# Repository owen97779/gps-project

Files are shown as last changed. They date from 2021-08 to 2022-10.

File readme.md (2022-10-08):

# GPS Project
## Introduction
The aim of the project is to design an open-source IoT-enabled GPS that can be used to provide coordinates at the behest of the user. The success of the device can be quantified by these factors:

### Hardware
- [ ] Open-source design
- [ ] Small form-factor and weight
- [ ] Durable
- [ ] Physical indicators of task completion
- [ ] ESD protection
- [ ] USB-C charging
- [ ] Wifi communication
- [ ] Cellular IoT communication
- [ ] Local storage
- [ ] Low power consumption
- [ ] Passing EMC tests
- [ ] Widely available and low cost components

### Software
- [ ] Open-source software
- [ ] OTA firmware updates
- [ ] Customisable GPS tracking intervals
- [ ] MQTT protocol adoption
- [ ] API integration

## Design
Multiple prototypes are being developed, each prototype with the aim of improving each design based on the limitations of the current in achieving the goals outlined above. The process can be viewed on [my blog](https://owen97779.github.io/GPS.html).

## Repository Branches
There are multiple branches working on different aspects of the project. Finalised builds will be merged onto the main branch.

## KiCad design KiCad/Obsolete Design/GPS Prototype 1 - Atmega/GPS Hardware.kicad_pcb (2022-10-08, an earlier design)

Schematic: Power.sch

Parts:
C1: 1u; C_0402_1005Metric_Pad0.74x0.62mm_HandSolder
C2, C6: 22u; C_0402_1005Metric_Pad0.74x0.62mm_HandSolder
C3: 47n; C_0402_1005Metric_Pad0.74x0.62mm_HandSolder
C4: 4u7; C_0402_1005Metric_Pad0.74x0.62mm_HandSolder
C5: 10u; C_0402_1005Metric_Pad0.74x0.62mm_HandSolder
C7: 220u; CP_EIA-3528-12_Kemet-T_Pad1.50x2.35mm_HandSolder
C8, C9: 0u1; C_0603_1608Metric_Pad1.08x0.95mm_HandSolder
D1: LED; LED_0603_1608Metric_Pad1.05x0.95mm_HandSolder
J1: USB_C_Receptacle_USB2.0; USB_C_Receptacle_HRO_TYPE-C-31-M-12
J5: B2B-XH-A(LF)(SN); JST_B2B-XH-A(LF)(SN); PARTREV 1.0
L1: 2u2; IND_SRP0312-2R2K
R1, R2: 5k1; R_0402_1005Metric_Pad0.72x0.64mm_HandSolder
R3, R4, R5: 4k7; R_0402_1005Metric_Pad0.72x0.64mm_HandSolder
R6, R7: 10k; R_0402_1005Metric_Pad0.72x0.64mm_HandSolder
R8: 250; R_0402_1005Metric_Pad0.72x0.64mm_HandSolder
R9: 10k; R_0603_1608Metric_Pad0.98x0.95mm_HandSolder
R10: 5k23; R_0402_1005Metric_Pad0.72x0.64mm_HandSolder
R11: 32k; R_0603_1608Metric_Pad0.98x0.95mm_HandSolder
TH1: Thermistor_NTC 10K; R_0805_2012Metric_Pad1.20x1.40mm_HandSolder
U1: ESD122DMX; IC_ESD122DMXR
U3: BQ24295; QFN50P400X400X100-25N
U4: LM3480-3.3; SOT-23

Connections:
D+: J1.A6 (D+), J1.B6 (D+), U1.1, U3.2
D-: J1.A7 (D-), J1.B7 (D-), U1.2, U3.3
GND: C1.2, C2.2, C4.2, C5.2, C6.2, C7.2, C8.2, C9.2, J1.A1 (GND), J1.A12 (GND), J1.B1 (GND), J1.B12 (GND), J1.S1 (SHIELD), J5.2, R1.1, R2.1, R6.2, R7.1, R11.2, TH1.2, U1.3, U3.17, U3.18, U3.25, U4.3 (GND); also elsewhere on the board
INT_Power: R5.1, U3.7; also elsewhere on the board
unnamed: C2.1, U3.23
unnamed: C3.1, U3.21
unnamed: C3.2, L1.1, U3.19, U3.20
unnamed: C4.1, R10.1, U3.22
unnamed: C5.1, J5.1, U3.13, U3.14
unnamed: D1.1 (K), R8.1
unnamed: J1.A5 (CC1), R1.2
unnamed: J1.B5 (CC2), R2.2
unnamed: R6.1, U3.9
unnamed: R7.2, U3.10
unnamed: R8.2, U3.4
unnamed: R9.1, U3.8
unnamed: R10.2, R11.1, TH1.1, U3.11
SCL_Power: R3.1, U3.5; also elsewhere on the board
SDA_Power: R4.2, U3.6; also elsewhere on the board
SYS: C6.1, C7.1, C8.1, D1.2 (A), L1.2, R9.2, U3.15, U3.16, U4.2 (VI); also elsewhere on the board
VBUS: C1.1, J1.A4 (VBUS), J1.A9 (VBUS), J1.B4 (VBUS), J1.B9 (VBUS), U3.1, U3.24

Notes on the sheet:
Check if switch is required
Different capacitor values for low impedance at a range of frequencies

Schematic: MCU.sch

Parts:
C10, C11, C12, C13, C16, C17: 0u1; C_0402_1005Metric_Pad0.74x0.62mm_HandSolder
C14, C15: 22p; C_0603_1608Metric_Pad1.08x0.95mm_HandSolder
J2: Conn_01x06_Male; PinHeader_2x03_P1.00mm_Vertical_SMD
R12, R13, R14: 330; R_0402_1005Metric_Pad0.72x0.64mm_HandSolder
R15: 10k; R_0402_1005Metric_Pad0.72x0.64mm_HandSolder
U5: ATmega328-AU; TQFP-32_7x7mm_P0.8mm
U6: SN74AVC4T774PW; SOP65P640X120-16N
Y1: Crystal; Crystal_SMD_HC49-SD

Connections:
+1V8: C16.1, U6.15; also elsewhere on the board
CTS: U5.1 (PD3), U6.3
CTS_Cellular: U6.13; also elsewhere on the board
GND: C10.2, C11.2, C12.2, C13.2, C14.1, C15.2, C16.2, C17.2, J2.4, U5.3 (GND), U5.5 (GND), U5.21 (GND), U6.1, U6.7, U6.9, U6.10; also elsewhere on the board
INT_Power: U5.9 (PD5); also elsewhere on the board
MISO: J2.3, R13.1
MOSI: J2.5, R12.1
unnamed: C10.1, U5.20 (AREF)
unnamed: C14.2, U5.7 (XTAL1/PB6), Y1.1
unnamed: C15.1, U5.8 (XTAL2/PB7), Y1.2
unnamed: R12.2, U5.15 (PB3)
unnamed: R13.2, U5.16 (PB4)
unnamed: R14.2, U5.17 (PB5)
PWR_Cellular: U5.26 (PC3); also elsewhere on the board
RESET: J2.6, R15.2, U5.29 (~RESET~/PC6)
RESET_Cellular: U5.25 (PC2); also elsewhere on the board
RTS: U5.32 (PD2), U6.4
RTS_Cellular: U6.14; also elsewhere on the board
RX: U5.30 (PD0), U6.5
RX_Cellular: U6.11; also elsewhere on the board
SCK: J2.1, R14.1
SCL_Power: U5.28 (PC5); also elsewhere on the board
SDA_Power: U5.27 (PC4); also elsewhere on the board
TX: U5.31 (PD1), U6.6
TX_Cellular: U6.12; also elsewhere on the board

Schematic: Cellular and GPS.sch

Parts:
C18: 10n; C_0402_1005Metric_Pad0.74x0.62mm_HandSolder
C19, C22, C23: 0u1; C_0402_1005Metric_Pad0.74x0.62mm_HandSolder
C20: 56p; C_0402_1005Metric_Pad0.74x0.62mm_HandSolder
C21: 15p; C_0402_1005Metric_Pad0.74x0.62mm_HandSolder
C25: 4u7; C_0402_1005Metric_Pad0.74x0.62mm_HandSolder
C27, C28, C29, C30: 47p; C_0402_1005Metric_Pad0.74x0.62mm_HandSolder
C31: 0u1; C_0603_1608Metric_Pad1.08x0.95mm_HandSolder
D2: LED; LED_0603_1608Metric_Pad1.05x0.95mm_HandSolder
D3, D4, D5, D6: PESD0402; C_0402_1005Metric_Pad0.74x0.62mm_HandSolder
J3: Conn_Coaxial; RFSOLUTIONS_CON-SMA-EDGE-S
Q1, Q2: BC847; SOT-23
Q3: BSS84; SOT-323_SC-70
R16: 100k; R_0402_1005Metric_Pad0.72x0.64mm_HandSolder
R17: 10k; R_0603_1608Metric_Pad0.98x0.95mm_HandSolder
R18: 47k; R_0603_1608Metric_Pad0.98x0.95mm_HandSolder
R19: 250; R_0603_1608Metric_Pad0.98x0.95mm_HandSolder
R20: 47k; R_0402_1005Metric_Pad0.72x0.64mm_HandSolder
U7: 74AVC2T245GU-Q100X; QFN40P140X180X50-10N
U8: SARA-U201; ublox_SARA-G3_LGA-96
U10: ublox_SAM-M8Q

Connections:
+1V8: C22.1, U7.6, U8.4 (V_INT); also elsewhere on the board
CLK: C28.1, D4.2 (A2), U8.38 (SIM_CLK); also elsewhere on the board
CTS_Cellular: U8.11 (CTS); also elsewhere on the board
EXTINT: U7.9, U10.19 (EXTINT)
GND: C18.2, C19.2, C20.2, C21.2, C22.2, C23.2, C25.2, C27.2, C28.2, C29.2, C30.2, C31.2, D3.1 (A1), D4.1 (A1), D5.1 (A1), D6.2 (A2), J3.2 (Ext), Q1.2 (E), Q2.2 (E), R18.2, U7.1, U7.2, U7.3, U8.1 (GND), U8.3 (GND), U8.5 (GND), U8.9 (DTR), U8.14 (GND), U8.20 (GND), U8.21 (GND), U8.22 (GND), U8.30 (GND), U8.32 (GND), U8.43 (GND), U8.50 (GND), U8.54 (GND), U8.55 (GND), U8.57 (GND), U8.58 (GND), U8.59 (GND), U8.60 (GND), U8.61 (GND), U8.63 (GND), U8.64 (GND), U8.65 (GND), U8.66 (GND), U8.67 (GND), U8.68 (GND), U8.69 (GND), U8.70 (GND), U8.71 (GND), U8.72 (GND), U8.73 (GND), U8.74 (GND), U8.75 (GND), U8.76 (GND), U8.77 (GND), U8.78 (GND), U8.79 (GND), U8.80 (GND), U8.81 (GND), U8.82 (GND), U8.83 (GND), U8.84 (GND), U8.85 (GND), U8.86 (GND), U8.87 (GND), U8.88 (GND), U8.89 (GND), U8.90 (GND), U8.91 (GND), U8.92 (GND), U8.93 (GND), U8.94 (GND), U8.95 (GND), U8.96 (GND), U10.1 (GND), U10.4 (GND), U10.5 (GND), U10.6 (GND), U10.10 (GND), U10.11 (GND), U10.15 (GND), U10.16 (GND), U10.20 (GND); also elsewhere on the board
GPIO2: Q2.1 (B), U8.23 (GPIO2)
GPIO3: U7.5, U8.24 (GPIO3)
GPIO4: U7.4, U8.25 (GPIO4)
IO: C29.1, D5.2 (A2), U8.39 (SIM_IO); also elsewhere on the board
unnamed: D2.1 (K), Q1.3 (C)
unnamed: D2.2 (A), R19.2
unnamed: J3.1 (In), U8.56 (ANT)
unnamed: Q1.1 (B), R17.2, R18.1
unnamed: Q2.3 (C), Q3.1 (G), R20.2
unnamed: R17.1, U8.16 (GPIO1)
PWR_Cellular: R16.2, U8.15 (PWR_ON); also elsewhere on the board
RESET_Cellular: U8.18 (~RESET); also elsewhere on the board
RST: C27.1, D3.2 (A2), U8.40 (SIM_RST); also elsewhere on the board
RTS_Cellular: U8.10 (RTS); also elsewhere on the board
RX_Cellular: U8.13 (RXD); also elsewhere on the board
SYS: C18.1, C19.1, C20.1, C21.1, R19.1, U8.51 (VCC), U8.52 (VCC), U8.53 (VCC); also elsewhere on the board
TX_Cellular: U8.12 (TXD); also elsewhere on the board
TX_GPS: U7.8, U10.13 (TXD)
VCC_GPS: C23.1, C25.1, Q3.3 (D), U7.7, U7.10, U10.2 (VCC_IO), U10.3 (V_BCKP), U10.17 (VCC)
VSIM: C30.1, C31.1, D6.1 (A1), U8.41 (VSIM); also elsewhere on the board

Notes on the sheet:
GPIO2 Pin has a 1ma output, no need for a resistor

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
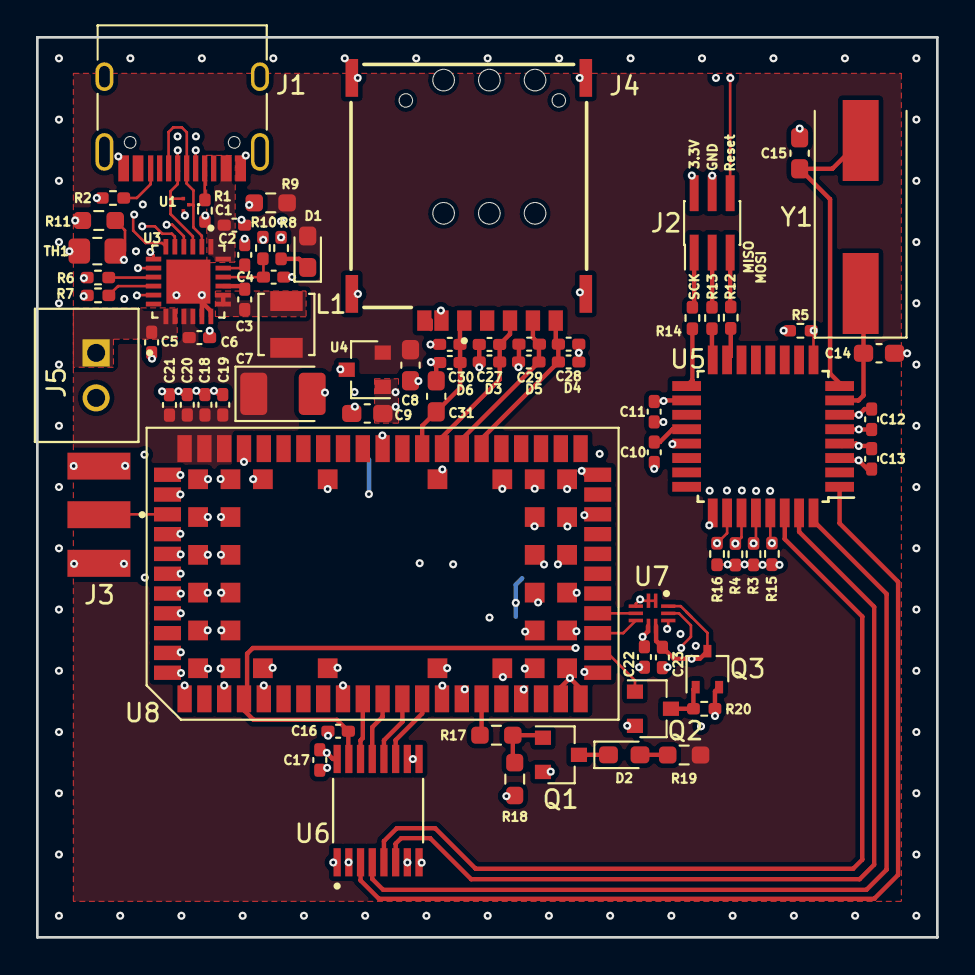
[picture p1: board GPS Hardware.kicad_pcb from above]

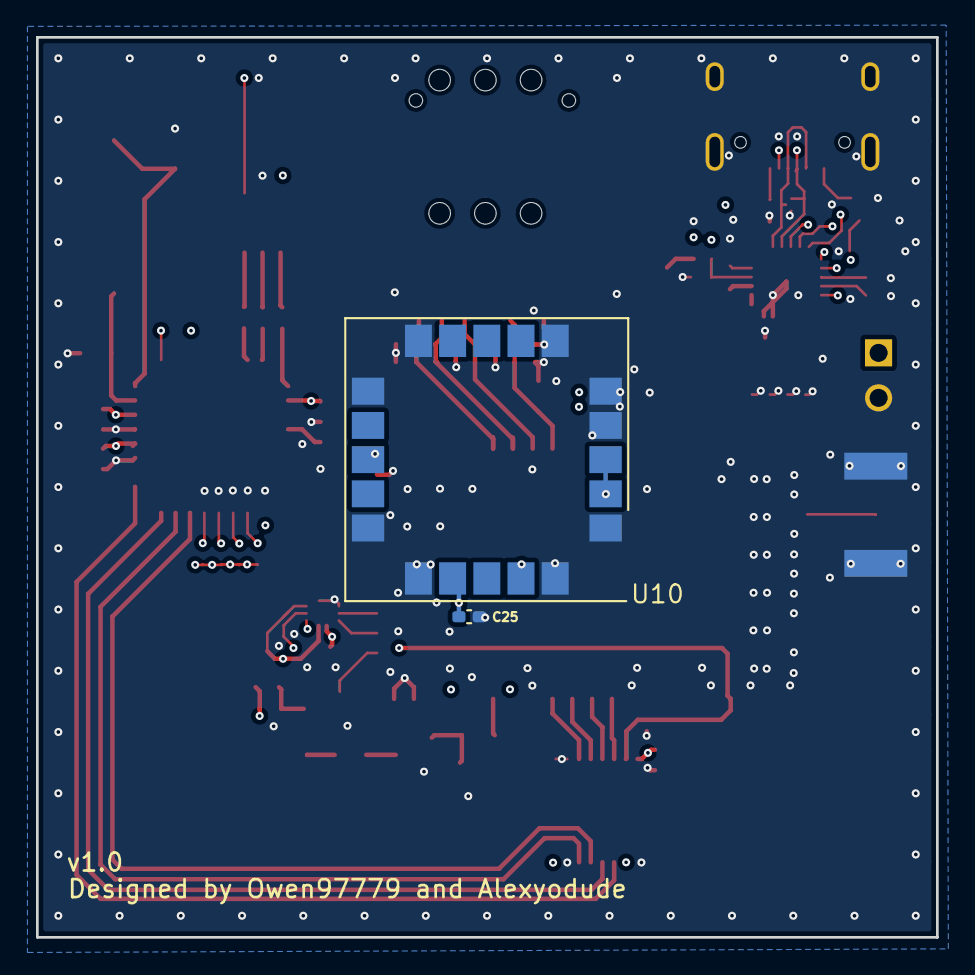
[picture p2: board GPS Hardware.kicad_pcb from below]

Board: 4 copper layers, 50.0 x 50.0 mm, 74 parts (2 on the bottom side), 59 nets.

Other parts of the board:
J4: SIM8065-6-1-14-01-A_REVA1; GCT_SIM8065-6-1-14-01-A_REVA1

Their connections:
CLK: J4.C3; also elsewhere on the board
GND: J4.C5, J4.G1, J4.G2, J4.G3, J4.G4; also elsewhere on the board
IO: J4.C7; also elsewhere on the board
RST: J4.C2; also elsewhere on the board
VSIM: J4.C1; also elsewhere on the board

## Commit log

2021-08-18 Added KiCad project files
    [GPS Hardware.kicad_pcb, GPS Hardware.sch]
2021-08-19 Added new schematics that aren't done yet
    [Cellular and GPS.sch, MCU.sch, Power.sch]
2021-08-21 Finished adding components, need to add values
    [Cellular and GPS.sch, MCU.sch, Power.sch]
2021-08-22 Update, 21st August
    [MCU.sch, Power.sch]
2021-08-22 Added footprints to most components
    [Cellular and GPS.sch, MCU.sch, Power.sch]
2021-08-22 Added all footprints
    Hopefully they are correct :)
    [Cellular and GPS.sch, GPS Hardware.kicad_pcb, MCU.sch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]
2021-08-22 Started pcb layout
    [GPS Hardware.kicad_pcb]
2021-08-24 Update for PC
    [GPS Hardware.kicad_pcb, MCU.sch]
2021-08-25 Update for PC again
    [GPS Hardware.kicad_pcb]
2021-08-26 Update to laptop
    [Cellular and GPS.sch, GPS Hardware.kicad_pcb, Power.sch]
2021-08-28 Update once again
    [GPS Hardware.kicad_pcb, MCU.sch]
2021-08-29 Update (again :+1: )
    [Cellular and GPS.sch, GPS Hardware.kicad_pcb, MCU.sch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]
2021-08-29 Update once more
    [GPS Hardware.kicad_pcb]
2021-08-30 Update dude
    [GPS Hardware.kicad_pcb]
2021-08-31 Update to PC
    [GPS Hardware.kicad_pcb, MCU.sch]
2021-08-31 Update PC
    [GPS Hardware.kicad_pcb, MCU.sch]
2021-09-03 Update to laptop
    Yay
    [GPS Hardware.kicad_pcb]
2021-09-04 Update layout once again
    1. SIG/POWER (3.8v)
    2. GROUND
    3. SIG/POWER (3.3v)
    4. GROUND
    [GPS Hardware.kicad_pcb]
2021-09-04 Update again
    Put some copper pour down as a test.
    [GPS Hardware.kicad_pcb]
2021-09-05 Test
    Commit
    [GPS Hardware.kicad_pcb]
2021-09-06 Update for today
    Just added a couple sim power lines to see how it will affect the 3v3 plane
    [GPS Hardware.kicad_pcb]
2021-09-11 Update to laptop
    Hopefully it works
    [GPS Hardware.kicad_pcb]
2021-09-16 Update to Laptop
    Properly
    [GPS Hardware.kicad_pcb]
2021-09-21 Update to laptop
    You need to finish gnd via placement
    [GPS Hardware.kicad_pcb]
2021-09-24 Update to PC Remember to double-check pads
    [GPS Hardware.kicad_pcb]
2021-09-26 Update from laptop
    [GPS Hardware.kicad_pcb]
2021-10-13 Update from university
    [GPS Hardware.kicad_pcb]
2021-10-15 Updated silkscreen
    [GPS Hardware.kicad_pcb]
2021-10-15 Finishing touches
    [GPS Hardware.kicad_pcb]
2021-10-18 Changed via placement and all that jazz
    [GPS Hardware.kicad_pcb]
2021-10-18 Updated the sim choice to a push-push type, and generated the final gerber files
    [Cellular and GPS.sch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]
2021-10-26 Changed resistor values for LEDs
    [Cellular and GPS.sch, GPS Hardware.kicad_pcb, Power.sch]
2022-02-23 Created a second prototype, continue to finish it
    [Cellular and GPS.sch, GPS Hardware.kicad_pcb, GPS Hardware.sch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]
2022-03-03 Delete KiCad/GPS Hardware directory
    Cleanup
    [Cellular and GPS.sch, GPS Hardware.kicad_pcb, GPS Hardware.sch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]
2022-03-08 Connected all the PCB connections and 20h distance
    [GPS Hardware.kicad_pcb]
2022-06-05 Update
    5th June 2022, change the LDO and other components next time.
    [Cellular and GPS.sch, GPS Hardware.kicad_pcb, GPS Hardware.sch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]
2022-06-08 Alvin house Mo update
    Have your kicad update
    [GPS Hardware.kicad_pcb]
2022-06-09 Some extra save stuff
    Some extra save stuff
    [Power.sch]
2022-06-22 Push to laptop
    Add traces etc.
    [GPS Hardware.kicad_pcb]
2022-06-27 Update to Uni computers
    Finish esp32 connections.
    [GPS Hardware.kicad_pcb, MCU.sch, Power.sch]
2022-06-27 Update from Uni
    [GPS Hardware.kicad_pcb, GPS Prototype 2.kicad_pcb, GPS Prototype 2.sch]
2022-07-10 Update to Laptop
    Still a lot more to go
    [Cellular and GPS.sch, GPS Hardware.kicad_pcb, MCU.sch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]
2022-10-08 Simplification of repo
    [Cellular and GPS.sch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]
2022-10-08 Cleansed the main branch
    [Cellular and GPS.sch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]

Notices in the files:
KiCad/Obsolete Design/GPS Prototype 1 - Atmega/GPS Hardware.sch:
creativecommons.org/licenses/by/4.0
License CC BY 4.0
